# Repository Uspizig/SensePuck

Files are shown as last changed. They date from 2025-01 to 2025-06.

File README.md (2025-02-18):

# SensePuck: The Addon Board for the Seeed Round Display

<p align="center"> 
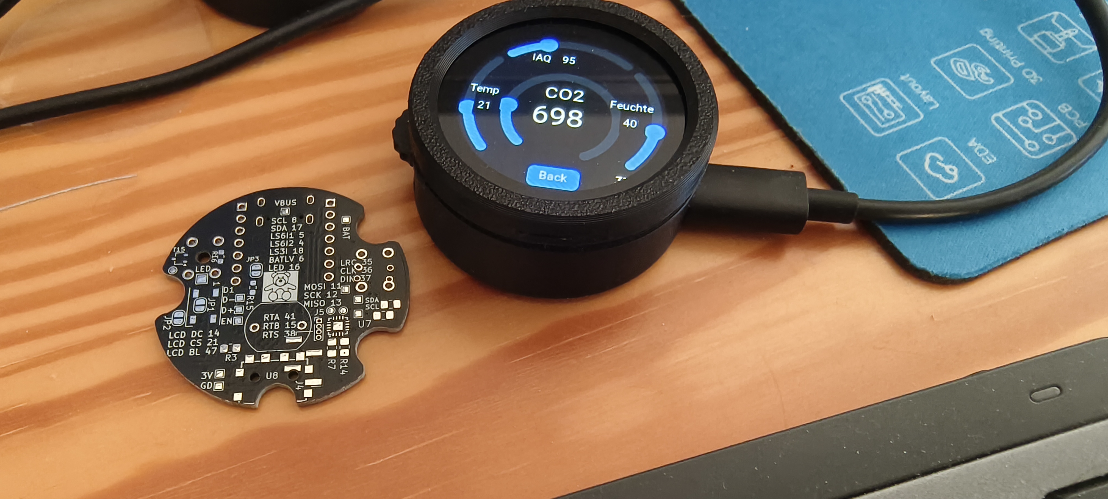
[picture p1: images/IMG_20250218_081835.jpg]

</p>

<p align="center"> 
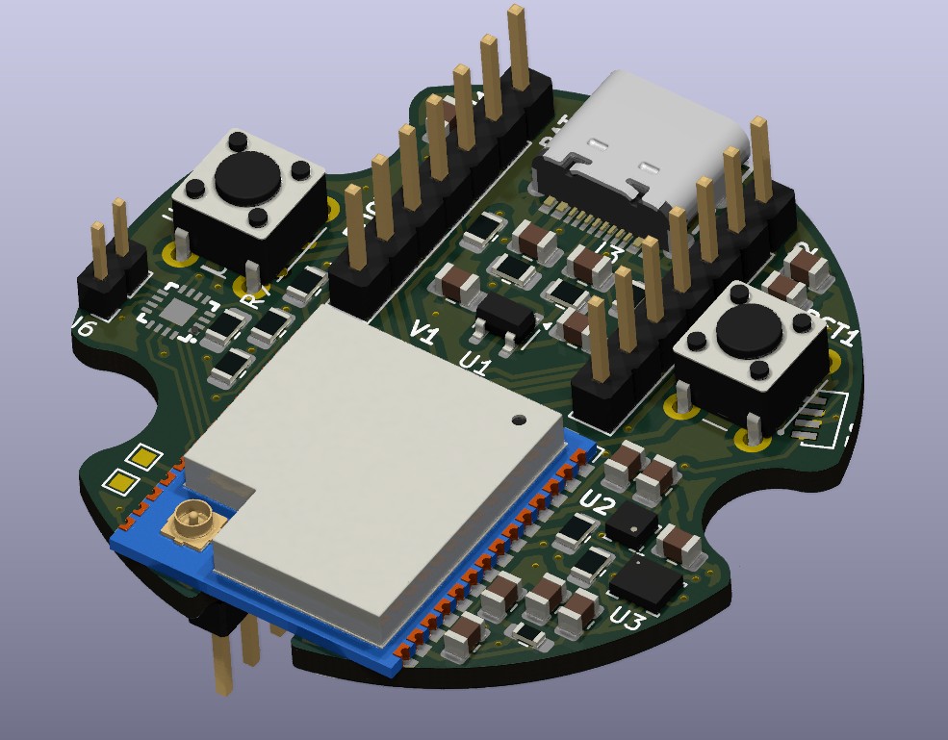
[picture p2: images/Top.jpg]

</p>

 <p align="center"> 
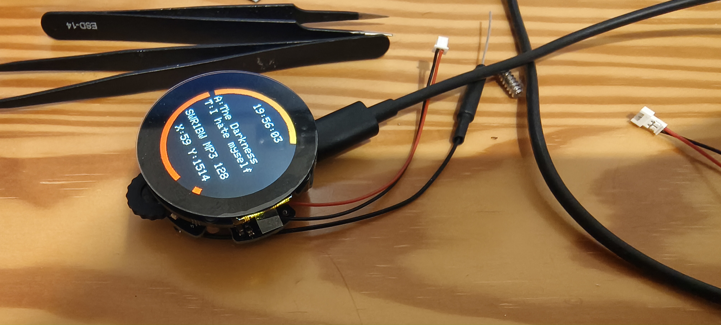
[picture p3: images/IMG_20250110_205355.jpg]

</p>

## Features:

1. **AudioAmplifier MAX98357**: Listen to your favourite Tunes with an Audio Amplifier

2. **I2C Connector for Sensor**: Connect your favourite I2C Sensor board with the embedded 2.54mm connector

3. **Wireless Control**: Untehther your development process with the wireless capabilities. With WiFi and BLE, this tool allows remote control and data logging. Users can adjust settings and monitor data from a distance, offering a more flexible development experience.

4. **LIS3M Magentometer**: Check your Heading

5. **LSM6 Gyro+ACC**: Check Movements, Steps Pedometer

5. **Open Source & Programmable**: As an open-source device, the Device offers unmatched versatility. It is fully programmable, allowing you to tailor its functionality to your specific applications. This customization extends to software and hardware, opening up endless possibilities for creative and efficient project development.

6. **Compact Design**: Designed for convenience, the LoRaCam Board compact and sleek form factor allows for seamless integration into existing setups. Its compatibility with USB PD power sources and inline integration capability minimizes the need for additional equipment or extensive redesign, making it a versatile and user-friendly addition to any development environment.

7. **Display+Touchscreeen**: Monitor live the current status on the Seeed Display

8. **RTC**: RealTimeClock from the Seeed Display
<p align="center"> 
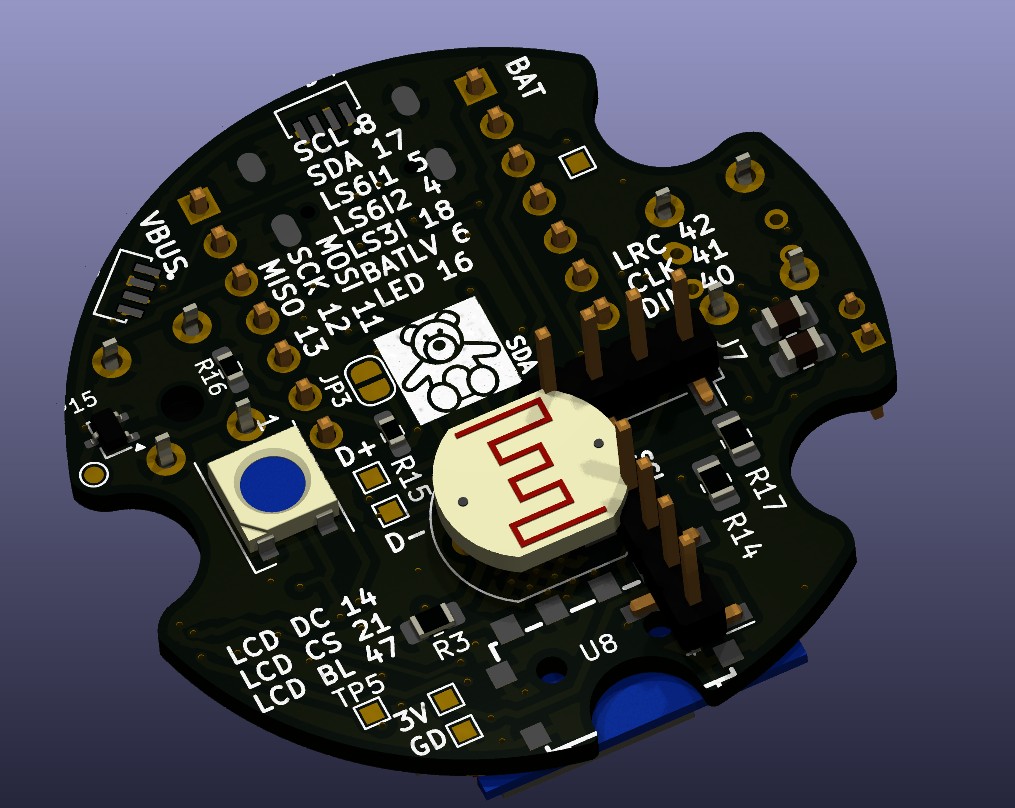
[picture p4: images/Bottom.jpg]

</p>

9. **RGB LED**: Status LED

10. **Battery Charger** Use the Battery Charger on the Seeed Display

11. **Rotary Encoder** Perfect for switching the Radio Station

12.  BME680: Measure Temperature, Humidity, Air Pressure, TVOC, eCO² (might update to BME688 or BME690 soon)
    
## Specifications

<p align="center"> 
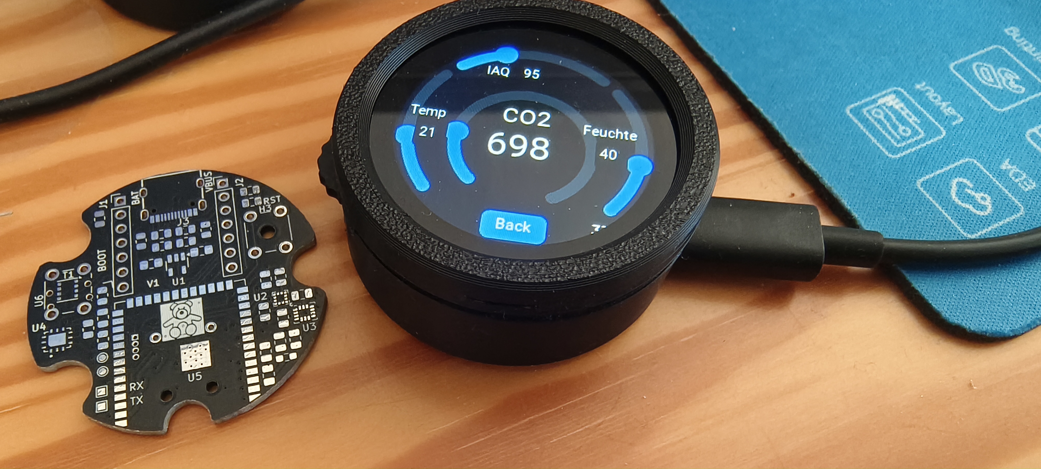
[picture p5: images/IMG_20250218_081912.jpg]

</p>

<p align="center"> 
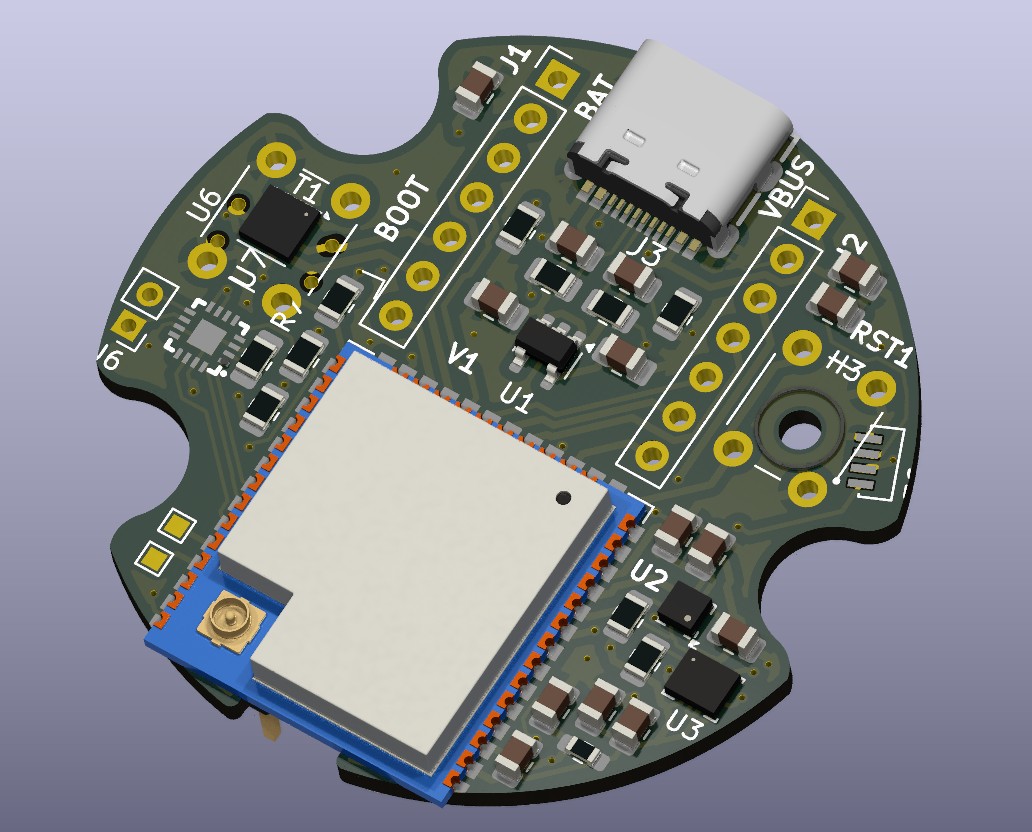
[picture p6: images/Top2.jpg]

</p>

<p align="center"> 
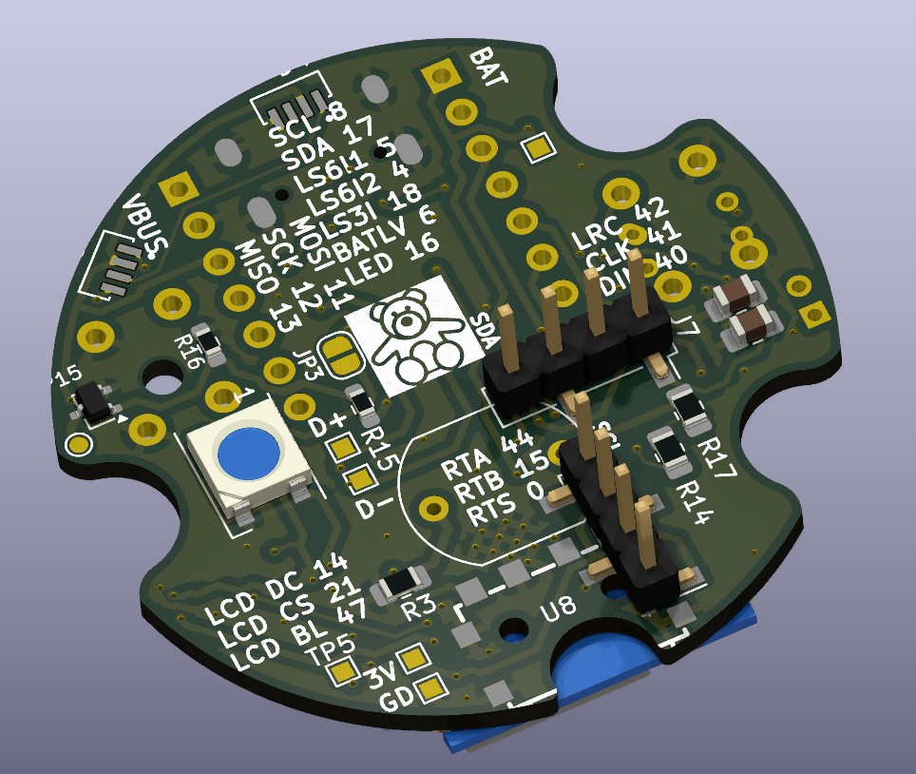
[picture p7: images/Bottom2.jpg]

</p>

<p align="center"> 
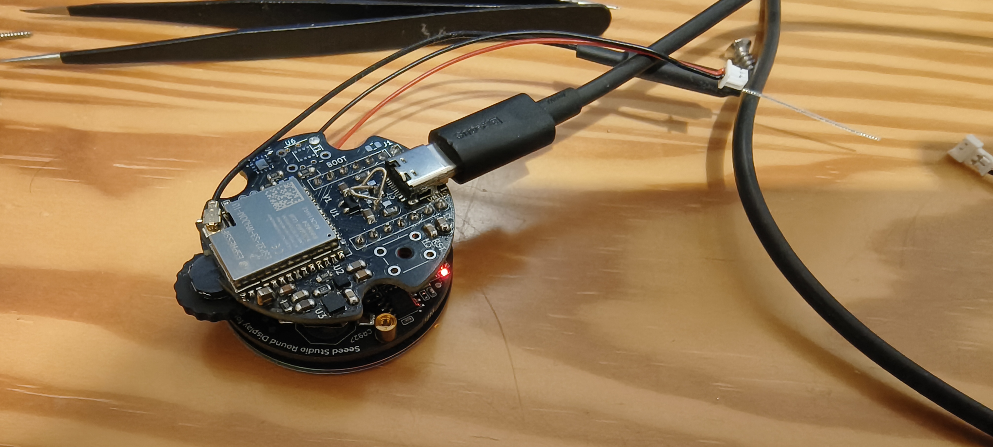
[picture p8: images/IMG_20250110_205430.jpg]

</p>

Needed Libaries:

https://github.com/schreibfaul1/ESP32-audioI2S
https://github.com/pololu/lis3mdl-arduino
https://github.com/pololu/lsm6-arduino
https://github.com/Seeed-Projects/SeeedStudio_TFT_eSPI
https://github.com/Seeed-Projects/SeeedStudio_lvgl
https://github.com/Seeed-Studio/Seeed_Arduino_RoundDisplay

### Key Features:

### Future Developments:

AI Detection of objects and determine if the device shall sent the data via LoRa 

## Testing for Performance

At the heart of SensePuck's design is a commitment to reliability and performance. To ensure that SensePuck stands up to real-world demands, we subjected it to testing under use conditions.

## License

MIT License

Copyright (c) 2025 blue2monster

Permission is hereby granted, free of charge, to any person obtaining a copy
of this software and associated documentation files (the "Software"), to deal
in the Software without restriction, including without limitation the rights
to use, copy, modify, merge, publish, distribute, sublicense, and/or sell
copies of the Software, and to permit persons to whom the Software is
furnished to do so, subject to the following conditions:

The above copyright notice and this permission notice shall be included in all
copies or substantial portions of the Software.

THE SOFTWARE IS PROVIDED "AS IS", WITHOUT WARRANTY OF ANY KIND, EXPRESS OR
IMPLIED, INCLUDING BUT NOT LIMITED TO THE WARRANTIES OF MERCHANTABILITY,
FITNESS FOR A PARTICULAR PURPOSE AND NONINFRINGEMENT. IN NO EVENT SHALL THE
AUTHORS OR COPYRIGHT HOLDERS BE LIABLE FOR ANY CLAIM, DAMAGES OR OTHER
LIABILITY, WHETHER IN AN ACTION OF CONTRACT, TORT OR OTHERWISE, ARISING FROM,
OUT OF OR IN CONNECTION WITH THE SOFTWARE OR THE USE OR OTHER DEALINGS IN THE
SOFTWARE.

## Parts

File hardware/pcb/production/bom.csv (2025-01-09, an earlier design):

Designator | Footprint | Quantity | Value | LCSC Part #
C1, C11, C12, C13, C14, C15, C16, C19, C6, C8, C9 | 0805 | 11 | 100nF
C10, C2, C3, C7 | 0805 | 4 | 1uF
C4, C5 | 0805 | 2 | DNP
D1 | LED_WS2812B_PLCC4_5.0x5.0mm_P3.2mm | 1 | WS2812B
J1 | PinHeader_1x07_P2.54mm_Vertical | 1 | DISP LEFT
J2 | PinHeader_1x07_P2.54mm_Vertical | 1 | DISP RIGHT
J3 | USB-C_SMD-TYPE-C-31-M-12 | 1 | TYPE-C-31-M-12
J4 | PinHeader_1x04_P2.54mm_Vertical_SMD_Pin1Left | 1 | Conn_01x04_Pin
J5 | PinHeader_1x04_P1.00mm_Vertical | 1 | Conn_01x04_Pin
JP3 | SolderJumper-2_P1.3mm_Open_RoundedPad1.0x1.5mm | 1 | Jumper_2_Small_Open
LED | TestPoint_Pad_1.5x1.5mm | 1 | LED
Q1 | SOT-323_SC-70 | 1 | SI1308EDL
R1, R15, R16 | 0603 | 3 | 10k
R10, R11, R12, R13, R4 | 0805 | 5 | 10k
R14 | 0805 | 1 | 300k
R2 | R_LDR_10x8.5mm_P7.6mm_Vertical | 1 | LDR03
R3 | 0805 | 1 | N.C.
R5, R6 | 0805 | 2 | 5k1
R7 | 0805 | 1 | 100K
R8, R9 | 0805 | 2 | 22R
RST | SW_PUSH_6mm | 1 | RST
RX | TestPoint_Pad_1.0x1.0mm | 1 | RXD
SW1 | SW_PUSH_6mm | 1 | BOOT
T1 | MLX90640 | 1 | MLX90640
T15, TP11, TP12, TP13, TP14 | TestPoint_Pad_D1.0mm | 5 | TestPoint
TP1 | TestPoint_Pad_1.0x1.0mm | 1 | D-
TP10 | TestPoint_Pad_1.0x1.0mm | 1 | BATT
TP2 | TestPoint_Pad_1.0x1.0mm | 1 | D+
TP3 | TestPoint_Pad_1.0x1.0mm | 1 | 3V3
TP4 | TestPoint_Pad_1.0x1.0mm | 1 | GND
TP5 | TestPoint_Pad_1.0x1.0mm | 1 | EN
TP6 | TestPoint_Pad_1.0x1.0mm | 1 | IO0
TP7 | TestPoint_Pad_1.0x1.0mm | 1 | SCL
TP8 | TestPoint_Pad_1.0x1.0mm | 1 | SDA
TP9 | TestPoint_Pad_1.0x1.0mm | 1 | VBUS
TX | TestPoint_Pad_1.0x1.0mm | 1 | TXD
U1 | SOT-23-5 | 1 | RT9013
U2 | LGA-12_2x2mm_P0.5mm | 1 | LIS3MDL
U3 | LGA-14_3x2.5mm_P0.5mm_LayoutBorder3x4y | 1 | LSM6DSOWTR
U4 | XDCR_STC31-C-R3 | 1 | STC31-C-R3
U5 | ESP32-S3-WROOM-1 | 1 | ESP32-S3-WROOM-1-Espressif
U6 | Bosch_LGA-8_3x3mm_P0.8mm_ClockwisePinNumbering | 1 | BME680
U7 | TQFN-16_L3.0-W3.0-P0.50-BL-EP1.5 | 1 | ~
U8 | SW-SMD_SIQ-02FVS3_1 | 1 | ~

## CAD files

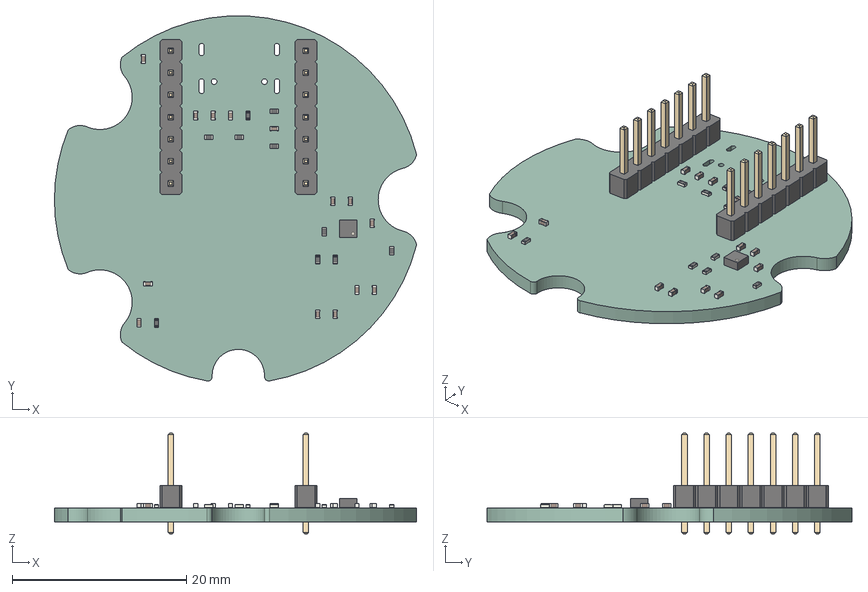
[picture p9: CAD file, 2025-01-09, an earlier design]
hardware/pcb/sensor_puck.step
41.6 x 41.9 x 11.5 mm
PinHeader_1x07_P254mm_Vertical x 2
C_0402_1005Metric x 14
R_0402_1005Metric x 10
LGA_12_2x2mm_P05mm
sensor_puck_PCB

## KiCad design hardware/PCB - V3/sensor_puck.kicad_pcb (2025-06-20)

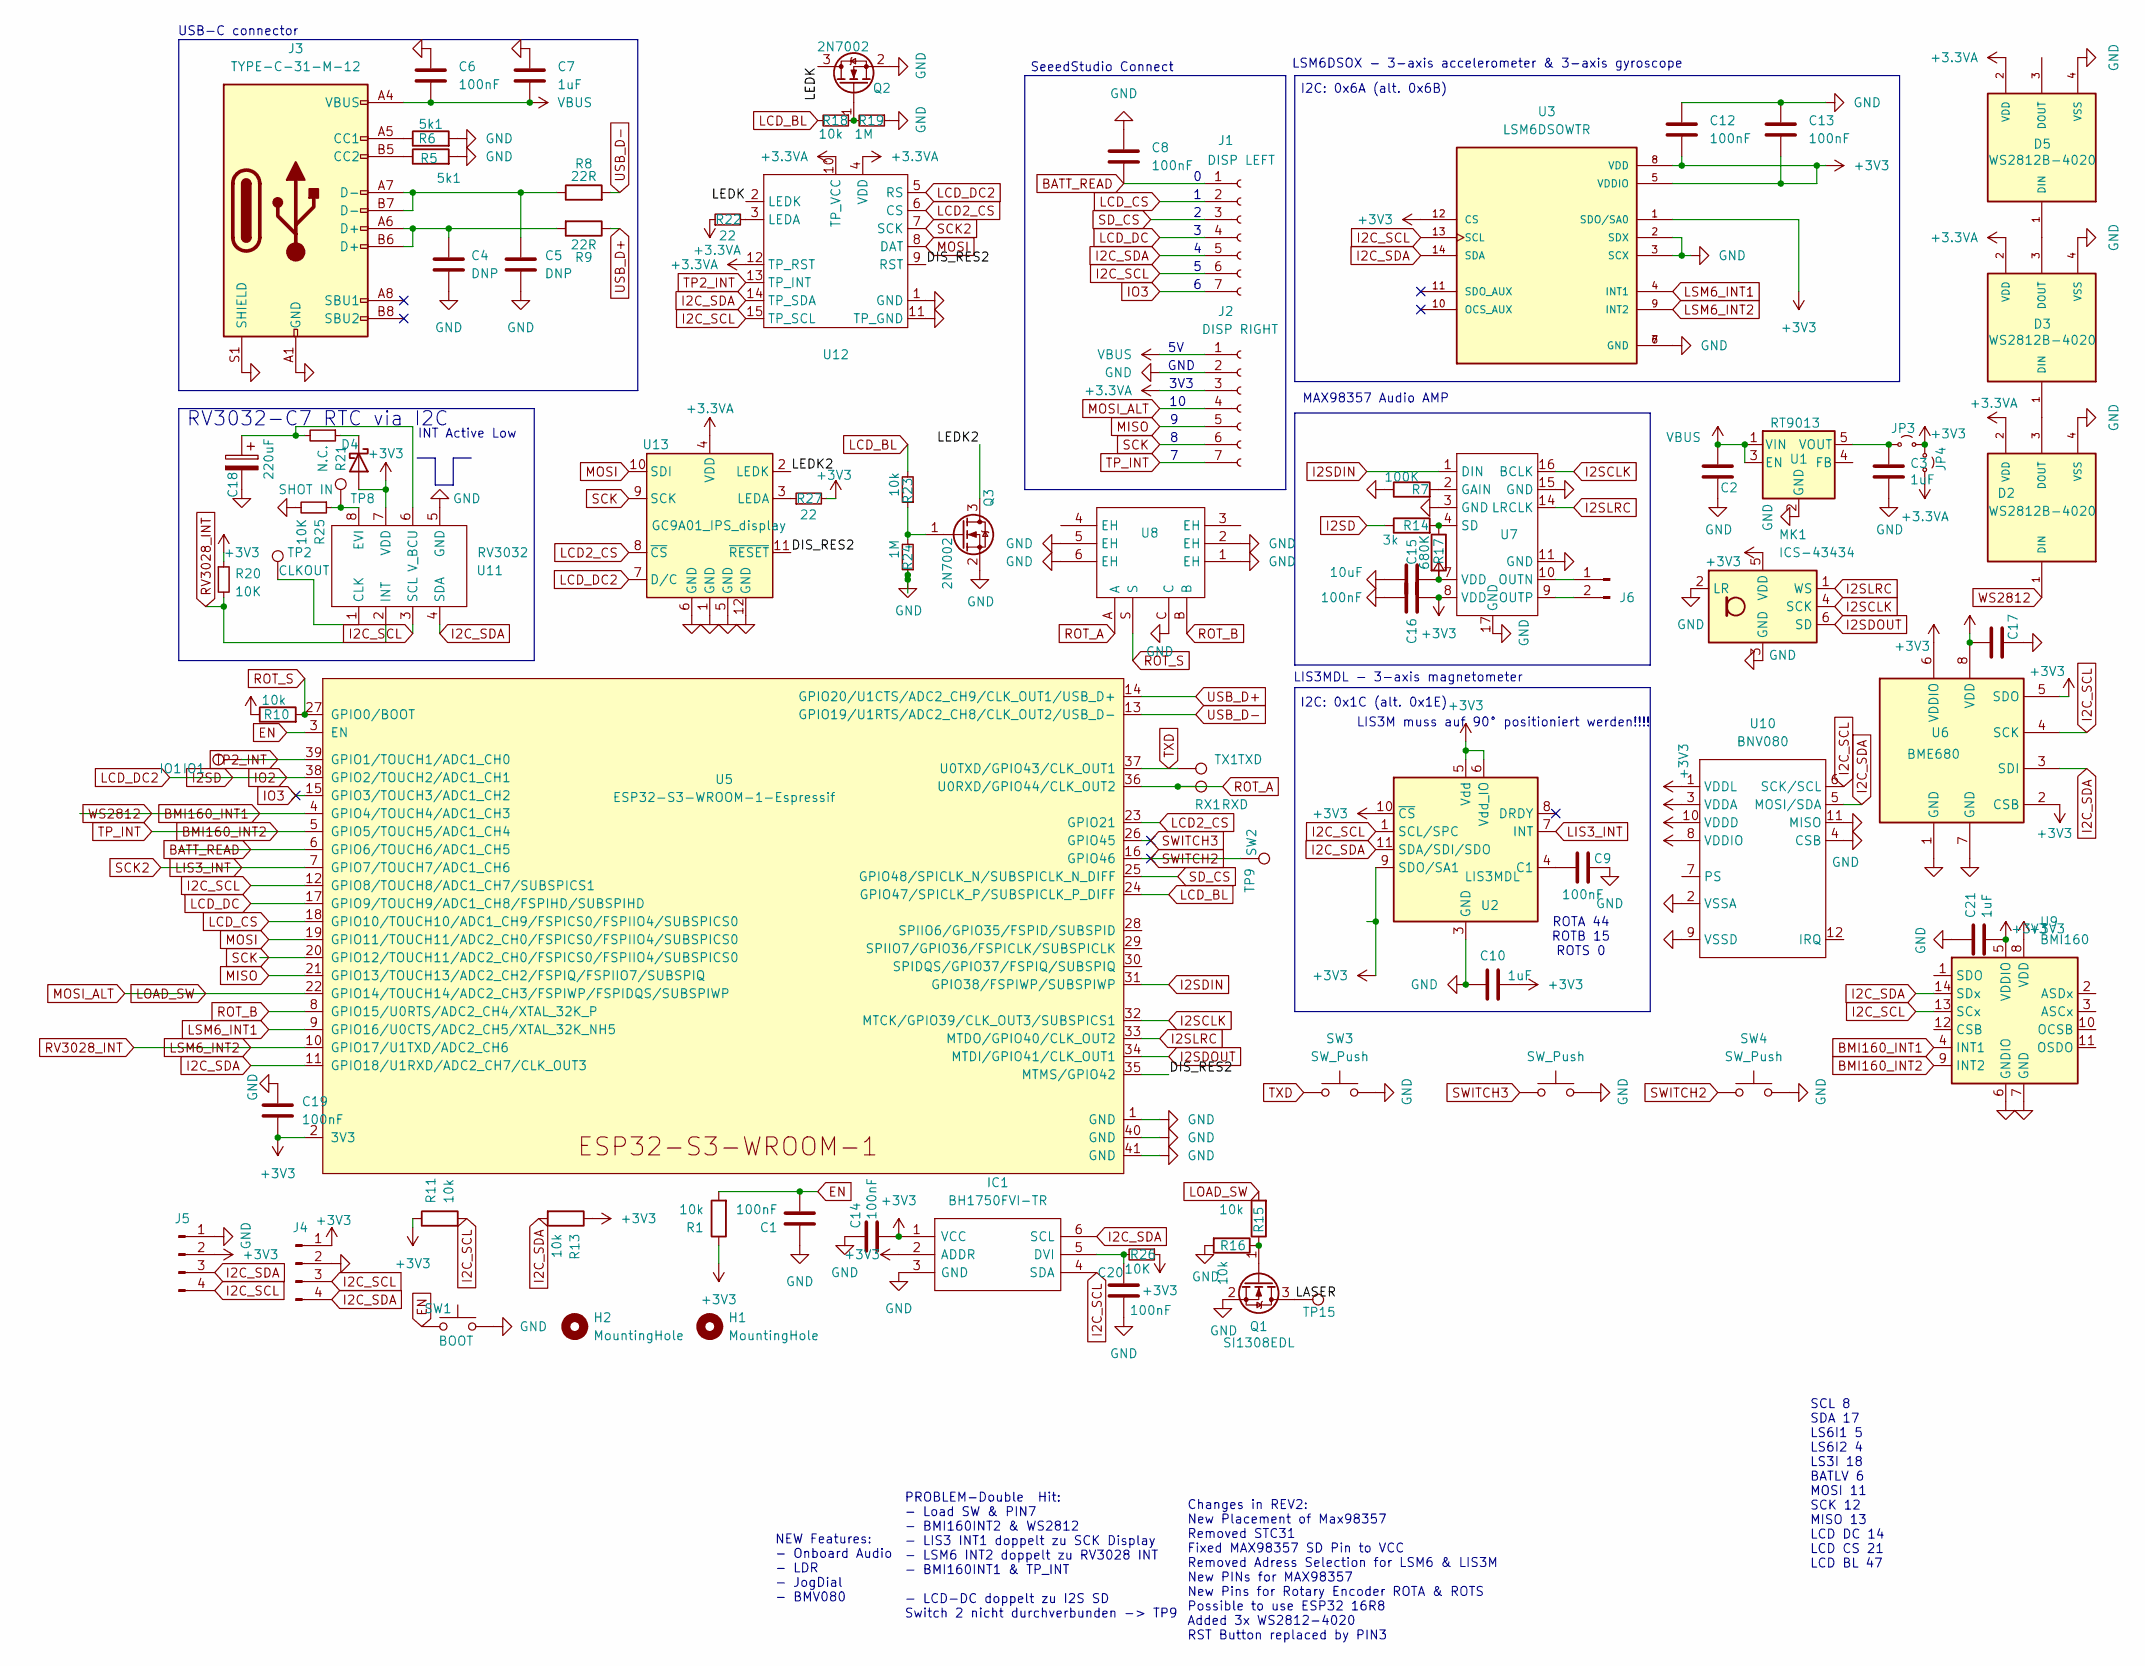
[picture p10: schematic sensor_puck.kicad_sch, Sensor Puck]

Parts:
C1: 100nF; C_1206_3216Metric_Pad1.33x1.80mm_HandSolder
C2, C3, C17, C21: 1uF; C_0805_2012Metric_Pad1.18x1.45mm_HandSolder
C4, C5: DNP; C_0805_2012Metric
C6, C8, C9, C12, C13, C14, C19: 100nF; C_0805_2012Metric
C7, C10: 1uF; C_0805_2012Metric
C15: 10uF; C_0805_2012Metric_Pad1.18x1.45mm_HandSolder
C16: 100nF; C_0805_2012Metric_Pad1.18x1.45mm_HandSolder
C18: 220uF; CP_EIA-3528-21_Kemet-B
C20: 100nF; C_0603_1608Metric
D2, D3, D5: WS2812B-4020; LED_WS2812B-4020; PARTREV V1.2
D4: MBR0530; D_SOD-323F
H1, H2: MountingHole; baerklein
IC1: BH1750FVI-TR; WSOF6; Mouser Part Number 755-BH1750FVI-TR
IO1: IO1; TestPoint_Pad_1.0x1.0mm
J1: DISP LEFT; PinHeader_1x07_P2.54mm_Vertical
J2: DISP RIGHT; PinHeader_1x07_P2.54mm_Vertical
J3: TYPE-C-31-M-12; USB-C_SMD-TYPE-C-31-M-12
J4: Conn_01x04_Pin; PinHeader_1x04_P2.54mm_Vertical_SMD_Pin1Left
J5: Conn_01x04_Pin; JST_SH_SM04B-SRSS-TB_1x04-1MP_P1.00mm_Horizontal
J6: Conn_01x02_Pin; PinHeader_1x02_P2.00mm_Vertical
JP3, JP4: Jumper_2_Small_Open; SolderJumper-2_P1.3mm_Open_RoundedPad1.0x1.5mm
MK1: ICS-43434; InvenSense_ICS-43434-6_3.5x2.65mm
Q1: SI1308EDL; SOT-323_SC-70
Q2, Q3: 2N7002; SOT-23
R1: 10k; R_0805_2012Metric_Pad1.20x1.40mm_HandSolder
R5, R6: 5k1; R_0805_2012Metric
R7: 100K; R_0805_2012Metric_Pad1.20x1.40mm_HandSolder
R8, R9: 22R; R_0805_2012Metric
R10, R11, R13: 10k; R_0805_2012Metric
R14: 3k; R_0805_2012Metric_Pad1.20x1.40mm_HandSolder
R15, R16: 10k; R_0603_1608Metric_Pad0.98x0.95mm_HandSolder
R17: 680K; R_0805_2012Metric_Pad1.20x1.40mm_HandSolder
R18, R23: 10k; R_0603_1608Metric
R19, R24: 1M; R_0603_1608Metric
R20, R25, R26: 10K; R_0603_1608Metric_Pad0.98x0.95mm_HandSolder; LCSC C17414
R21: N.C.; C_0603_1608Metric
R22, R27: 22; R_0603_1608Metric
RX1: RXD; TestPoint_Pad_1.0x1.0mm
SW1: BOOT; SW_PUSH_6mm
SW3, SW4, SW6: SW_Push; SW_SPST_CK_KMS2xxGP
TP2: CLKOUT; TestPoint_Pad_D1.0mm
TP8: SHOT IN; TestPoint_Pad_D1.0mm
TP9: SW2; TestPoint_Pad_D1.0mm
TP15: TestPoint; TestPoint_Pad_D1.0mm
TX1: TXD; TestPoint_Pad_1.0x1.0mm
U1: RT9013; SOT-23-5
U2: LIS3MDL; LGA-12_2x2mm_P0.5mm
U3: LSM6DSOWTR; LGA-14_3x2.5mm_P0.5mm_LayoutBorder3x4y; PARTREV 3.0
U5: ESP32-S3-WROOM-1-Espressif; ESP32-S3-WROOM-1
U6: BME680; Bosch_LGA-8_3x3mm_P0.8mm_ClockwisePinNumbering
U7: TQFN-16_L3.0-W3.0-P0.50-BL-EP1.5
U8: SW-SMD_SIQ-02FVS3_1; Manufacturer Part SIQ-02FVS3; LCSC Part Name 拨轮滚轮旋转编码器开关
U9: BMI160; Bosch_LGA-14_3x2.5mm_P0.5mm
U10: BNV080; 046844713002846
U11: RV3032; MicroCrystal_C7_SON-8_1.5x3.2mm_P0.9mm
U12: GC9A01_Touch_IPS_display_reversed_16pin
U13: GC9A01_IPS_display; GC9A01_IPS_display_reversed

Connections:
+3.3VA: D2.2 (VDD), D3.2 (VDD), D5.2 (VDD), J2.3, JP4.2 (B), R22.1, U12.4 (VDD), U12.10 (TP_VCC), U12.12 (TP_RST), U13.4 (VDD)
+3V3: C10.2, C12.2, C13.2, C14.2, C15.1, C16.1, C17.2, C19.2, C21.1, D4.2 (A), IC1.1 (VCC), IC1.2 (ADDR), J4.1, J5.2, JP3.2 (B), JP4.1 (A), MK1.5 (VDD), R1.1, R10.1, R11.1, R13.1, R17.2, R20.1, R26.1, R27.2, U2.5 (Vdd), U2.6 (Vdd_IO), U2.9 (SDO/SA1), U2.10 (~CS), U3.1 (SDO/SA0), U3.5 (VDDIO), U3.8 (VDD), U3.12 (CS), U5.2 (3V3), U6.2 (CSB), U6.5 (SDO), U6.6 (VDDIO), U6.8 (VDD), U7.7 (VDD), U7.8 (VDD), U9.5 (VDDIO), U9.8 (VDD), U10.1 (VDDL), U10.3 (VDDA), U10.8 (VDDIO), U10.10 (VDDD), U11.7 (VDD)
/DIS_RES2: U5.35 (MTMS/GPIO42), U12.9 (RST), U13.11 (~RESET)
/LASER: Q1.3 (D), TP15.1
/LEDK: Q2.3 (D), U12.2 (LEDK)
/LEDK2: Q3.3 (D), U13.2 (LEDK)
BATT_READ: C8.1, J1.1, U5.6 (GPIO6/TOUCH6/ADC1_CH5)
BMI160_INT1: D2.1 (DIN), U5.4 (GPIO4/TOUCH4/ADC1_CH3), U9.4 (INT1)
BMI160_INT2: J2.7, U5.5 (GPIO5/TOUCH5/ADC1_CH4), U9.9 (INT2)
EN: C1.2, R1.2, SW1.1, U5.3 (EN)
GND: C1.1, C2.1, C3.1, C4.2, C5.2, C6.1, C7.1, C8.2, C9.2, C10.1, C12.1, C13.1, C14.1, C15.2, C16.2, C17.1, C18.2, C19.1, C20.2, C21.2, D2.4 (VSS), D3.4 (VSS), D5.4 (VSS), IC1.3 (GND), J2.2, J3.A1 (GND), J3.A12 (GND), J3.B1 (GND), J3.B12 (GND), J3.S1 (SHIELD), J4.2, J5.1, MK1.2 (LR), MK1.3 (GND), Q1.2 (S), Q2.2 (S), Q3.2 (S), R5.2, R6.2, R7.1, R16.2, R19.1, R24.1, R25.2, SW1.2, SW3.2, SW4.2, SW6.2, U1.2 (GND), U2.2 (GND), U2.3 (GND), U2.12 (GND), U3.2 (SDX), U3.3 (SCX), U3.6 (GND), U3.7 (GND), U5.1 (GND), U5.40 (GND), U5.41 (GND), U6.1 (GND), U6.7 (GND), U7.3 (GND), U7.11 (GND), U7.15 (GND), U7.17 (GND), U8.1 (EH), U8.2 (EH), U8.5 (EH), U8.6 (EH), U8.C, U9.6 (GNDIO), U9.7 (GND), U10.2 (VSSA), U10.4 (CSB), U10.9 (VSSD), U10.11 (MISO), U11.5 (GND), U12.1 (GND), U12.11 (TP_GND), U13.1 (GND), U13.5 (GND), U13.6 (GND), U13.12 (GND)
I2C_SCL: IC1.4 (SDA), J1.6, J4.3, J5.4, R11.2, U2.1 (SCL/SPC), U3.13 (SCL), U5.12 (GPIO8/TOUCH8/ADC1_CH7/SUBSPICS1), U6.4 (SCK), U9.13 (SCx), U10.6 (SCK/SCL), U11.3 (SCL), U12.15 (TP_SCL)
I2C_SDA: IC1.6 (SCL), J1.5, J4.4, J5.3, R13.2, U2.11 (SDA/SDI/SDO), U3.14 (SDA), U5.11 (GPIO18/U1RXD/ADC2_CH7/CLK_OUT3), U6.3 (SDI), U9.14 (SDx), U10.5 (MOSI/SDA), U11.4 (SDA), U12.14 (TP_SDA)
I2SCLK: MK1.4 (SCK), U5.32 (MTCK/GPIO39/CLK_OUT3/SUBSPICS1), U7.16 (BCLK)
I2SD: R14.1, U5.38 (GPIO2/TOUCH2/ADC1_CH1), U12.5 (RS), U13.7 (D/C)
I2SDIN: U5.31 (GPIO38/FSPIWP/SUBSPIWP), U7.1 (DIN)
I2SDOUT: MK1.6 (SD), U5.34 (MTDI/GPIO41/CLK_OUT1)
I2SLRC: MK1.1 (WS), U5.33 (MTDO/GPIO40/CLK_OUT2), U7.14 (LRCLK)
IO3: J1.7, U5.15 (GPIO3/TOUCH3/ADC1_CH2)
LCD2_CS: U5.23 (GPIO21), U12.6 (CS), U13.8 (~CS)
LCD_BL: R18.2, R23.2, U5.24 (GPIO47/SPICLK_P/SUBSPICLK_P_DIFF)
LCD_CS: J1.2, U5.18 (GPIO10/TOUCH10/ADC1_CH9/FSPICS0/FSPIIO4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)
LCD_DC: J1.4, U5.17 (GPIO9/TOUCH9/ADC1_CH8/FSPIHD/SUBSPIHD)
LIS3_INT: U2.7 (INT), U5.7 (GPIO7/TOUCH7/ADC1_CH6), U12.7 (SCK)
LOAD_SW: J2.4, R15.2, U5.22 (GPIO14/TOUCH14/ADC2_CH3/FSPIWP/FSPIDQS/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)
LSM6_INT1: U3.4 (INT1), U5.9 (GPIO16/U0CTS/ADC2_CH5/XTAL_32K_NH5)
LSM6_INT2: R20.2, U3.9 (INT2), U5.10 (GPIO17/U1TXD/ADC2_CH6), U11.2 (INT)
MISO: J2.5, U5.21 (GPIO13/TOUCH13/ADC2_CH2/FSPIQ/FSPIIO7/S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)
MOSI: U5.19 (GPIO11/TOUCH11/ADC2_CH0/FSPICS0/FSPIIO4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), U12.8 (DAT), U13.10 (SDI)
unnamed: C4.1, J3.A6 (D+), J3.B6 (D+), R9.2
unnamed: C5.1, J3.A7 (D-), J3.B7 (D-), R8.1
unnamed: D2.3 (DOUT), D3.1 (DIN)
unnamed: D3.3 (DOUT), D5.1 (DIN)
unnamed: D4.1 (K), R21.1
unnamed: C20.1, IC1.5 (DVI), R26.2
unnamed: J3.A5 (CC1), R6.1
unnamed: J3.B5 (CC2), R5.1
unnamed: J6.1, U7.10 (OUTN)
unnamed: J6.2, U7.9 (OUTP)
unnamed: C3.2, JP3.1 (A), U1.5 (VOUT)
unnamed: Q1.1 (G), R15.1, R16.1
unnamed: Q2.1 (G), R18.1, R19.2
unnamed: Q3.1 (G), R23.1, R24.2
unnamed: C9.1, U2.4 (C1)
unnamed: R7.2, U7.2 (GAIN)
unnamed: R14.2, R17.1, U7.4 (SD)
unnamed: TP2.1, U11.1 (CLK)
unnamed: R25.1, TP8.1, U11.8 (EVI)
unnamed: C18.1, R21.2, U11.6 (V_BCU)
unnamed: R22.2, U12.3 (LEDA)
unnamed: R27.1, U13.3 (LEDA)
ROT_A: RX1.1, U5.36 (U0RXD/GPIO44/CLK_OUT2), U8.A
ROT_B: U5.8 (GPIO15/U0RTS/ADC2_CH4/XTAL_32K_P), U8.B
ROT_S: R10.2, U5.27 (GPIO0/BOOT), U8.S
SCK: J2.6, U5.20 (GPIO12/TOUCH11/ADC2_CH0/FSPICS0/FSPIIO4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), U13.9 (SCK)
SD_CS: J1.3, U5.25 (GPIO48/SPICLK_N/SUBSPICLK_N_DIFF)
SWITCH3: SW6.1, U5.26 (GPIO45)
TP2_INT: IO1.1, U5.39 (GPIO1/TOUCH1/ADC1_CH0), U12.13 (TP_INT)
TXD: SW3.1, TX1.1, U5.37 (U0TXD/GPIO43/CLK_OUT1)
USB_D+: R9.1, U5.14 (GPIO20/U1CTS/ADC2_CH9/CLK_OUT1/USB_D+)
USB_D-: R8.2, U5.13 (GPIO19/U1RTS/ADC2_CH8/CLK_OUT2/USB_D-)
VBUS: C2.2, C6.2, C7.2, J2.1, J3.A4 (VBUS), J3.A9 (VBUS), J3.B4 (VBUS), J3.B9 (VBUS), U1.1 (VIN), U1.3 (EN)

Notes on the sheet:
USB-C connector
PROBLEM-Double Hit: - Load SW & PIN7 - BMI160INT2 & WS2812 - LIS3 INT1 doppelt zu SCK Display - LSM6 INT2 doppelt zu RV3028 INT - BMI160INT1 & TP_INT - LCD-DC doppelt zu I2S SD Switch 2 nicht durchverbunden -> TP9
INT Active Low
LIS3M muss auf 90° positioniert werden!!!!
SeeedStudio Connect
SCL 8 SDA 17 LS6I1 5 LS6I2 4 LS3I 18 BATLV 6 MOSI 11 SCK 12 MISO 13 LCD DC 14 LCD CS 21 LCD BL 47
I2C: 0x1C (alt. 0x1E)
NEW Features: - Onboard Audio - LDR - JogDial - BMV080
Changes in REV2: New Placement of Max98357 Removed STC31 Fixed MAX98357 SD Pin to VCC Removed Adress Selection for LSM6 & LIS3M New PINs for MAX98357 New Pins for Rotary Encoder ROTA & ROTS Possible to use ESP32 16R8 Added 3x WS2812-4020 RST Button replaced by PIN3
I2C: 0x6A (alt. 0x6B)
LIS3MDL - 3-axis magnetometer
RV3032-C7 RTC via I2C
MAX98357 Audio AMP
GND
LSM6DSOX - 3-axis accelerometer & 3-axis gyroscope
ROTA 44 ROTB 15 ROTS 0
3V3

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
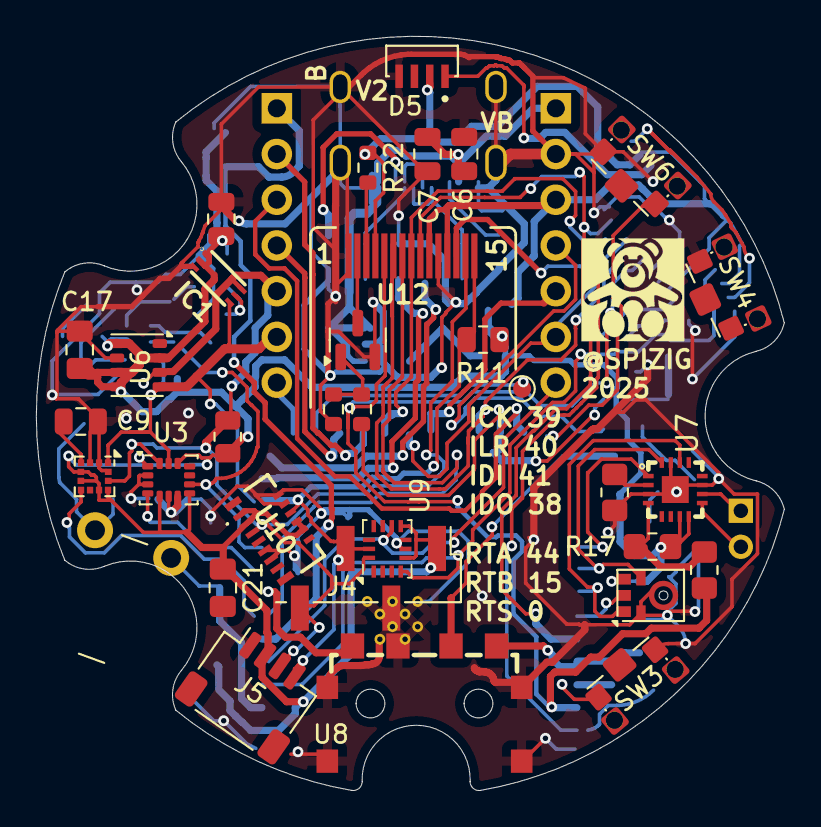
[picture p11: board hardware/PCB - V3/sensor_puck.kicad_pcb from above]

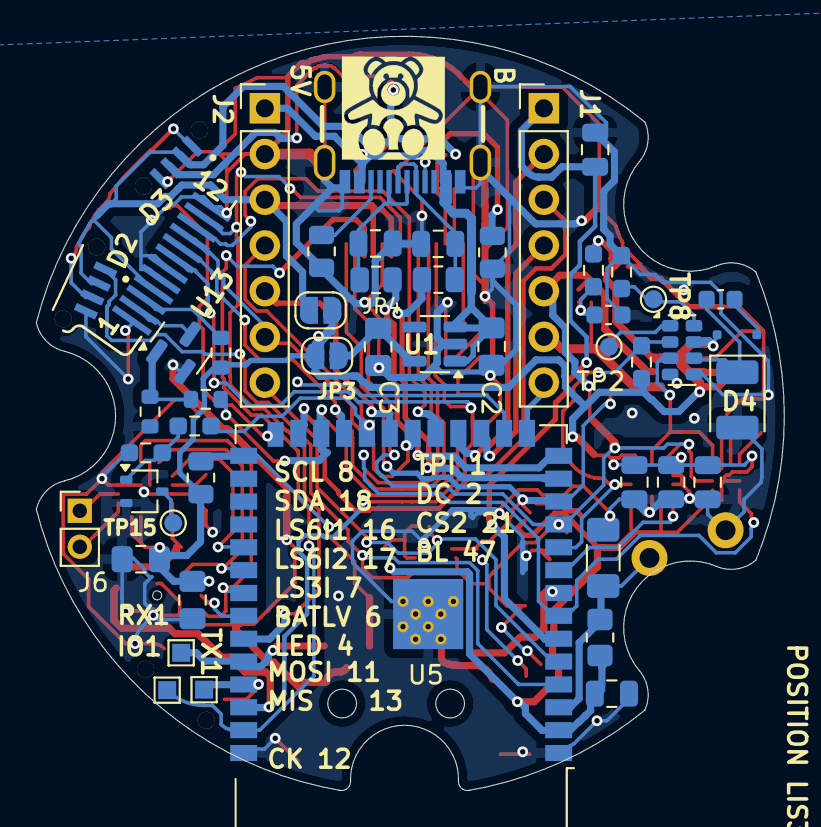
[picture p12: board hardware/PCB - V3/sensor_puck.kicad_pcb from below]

Board: 2 copper layers, 41.6 x 41.9 mm, 85 parts (51 on the bottom side), 63 nets.

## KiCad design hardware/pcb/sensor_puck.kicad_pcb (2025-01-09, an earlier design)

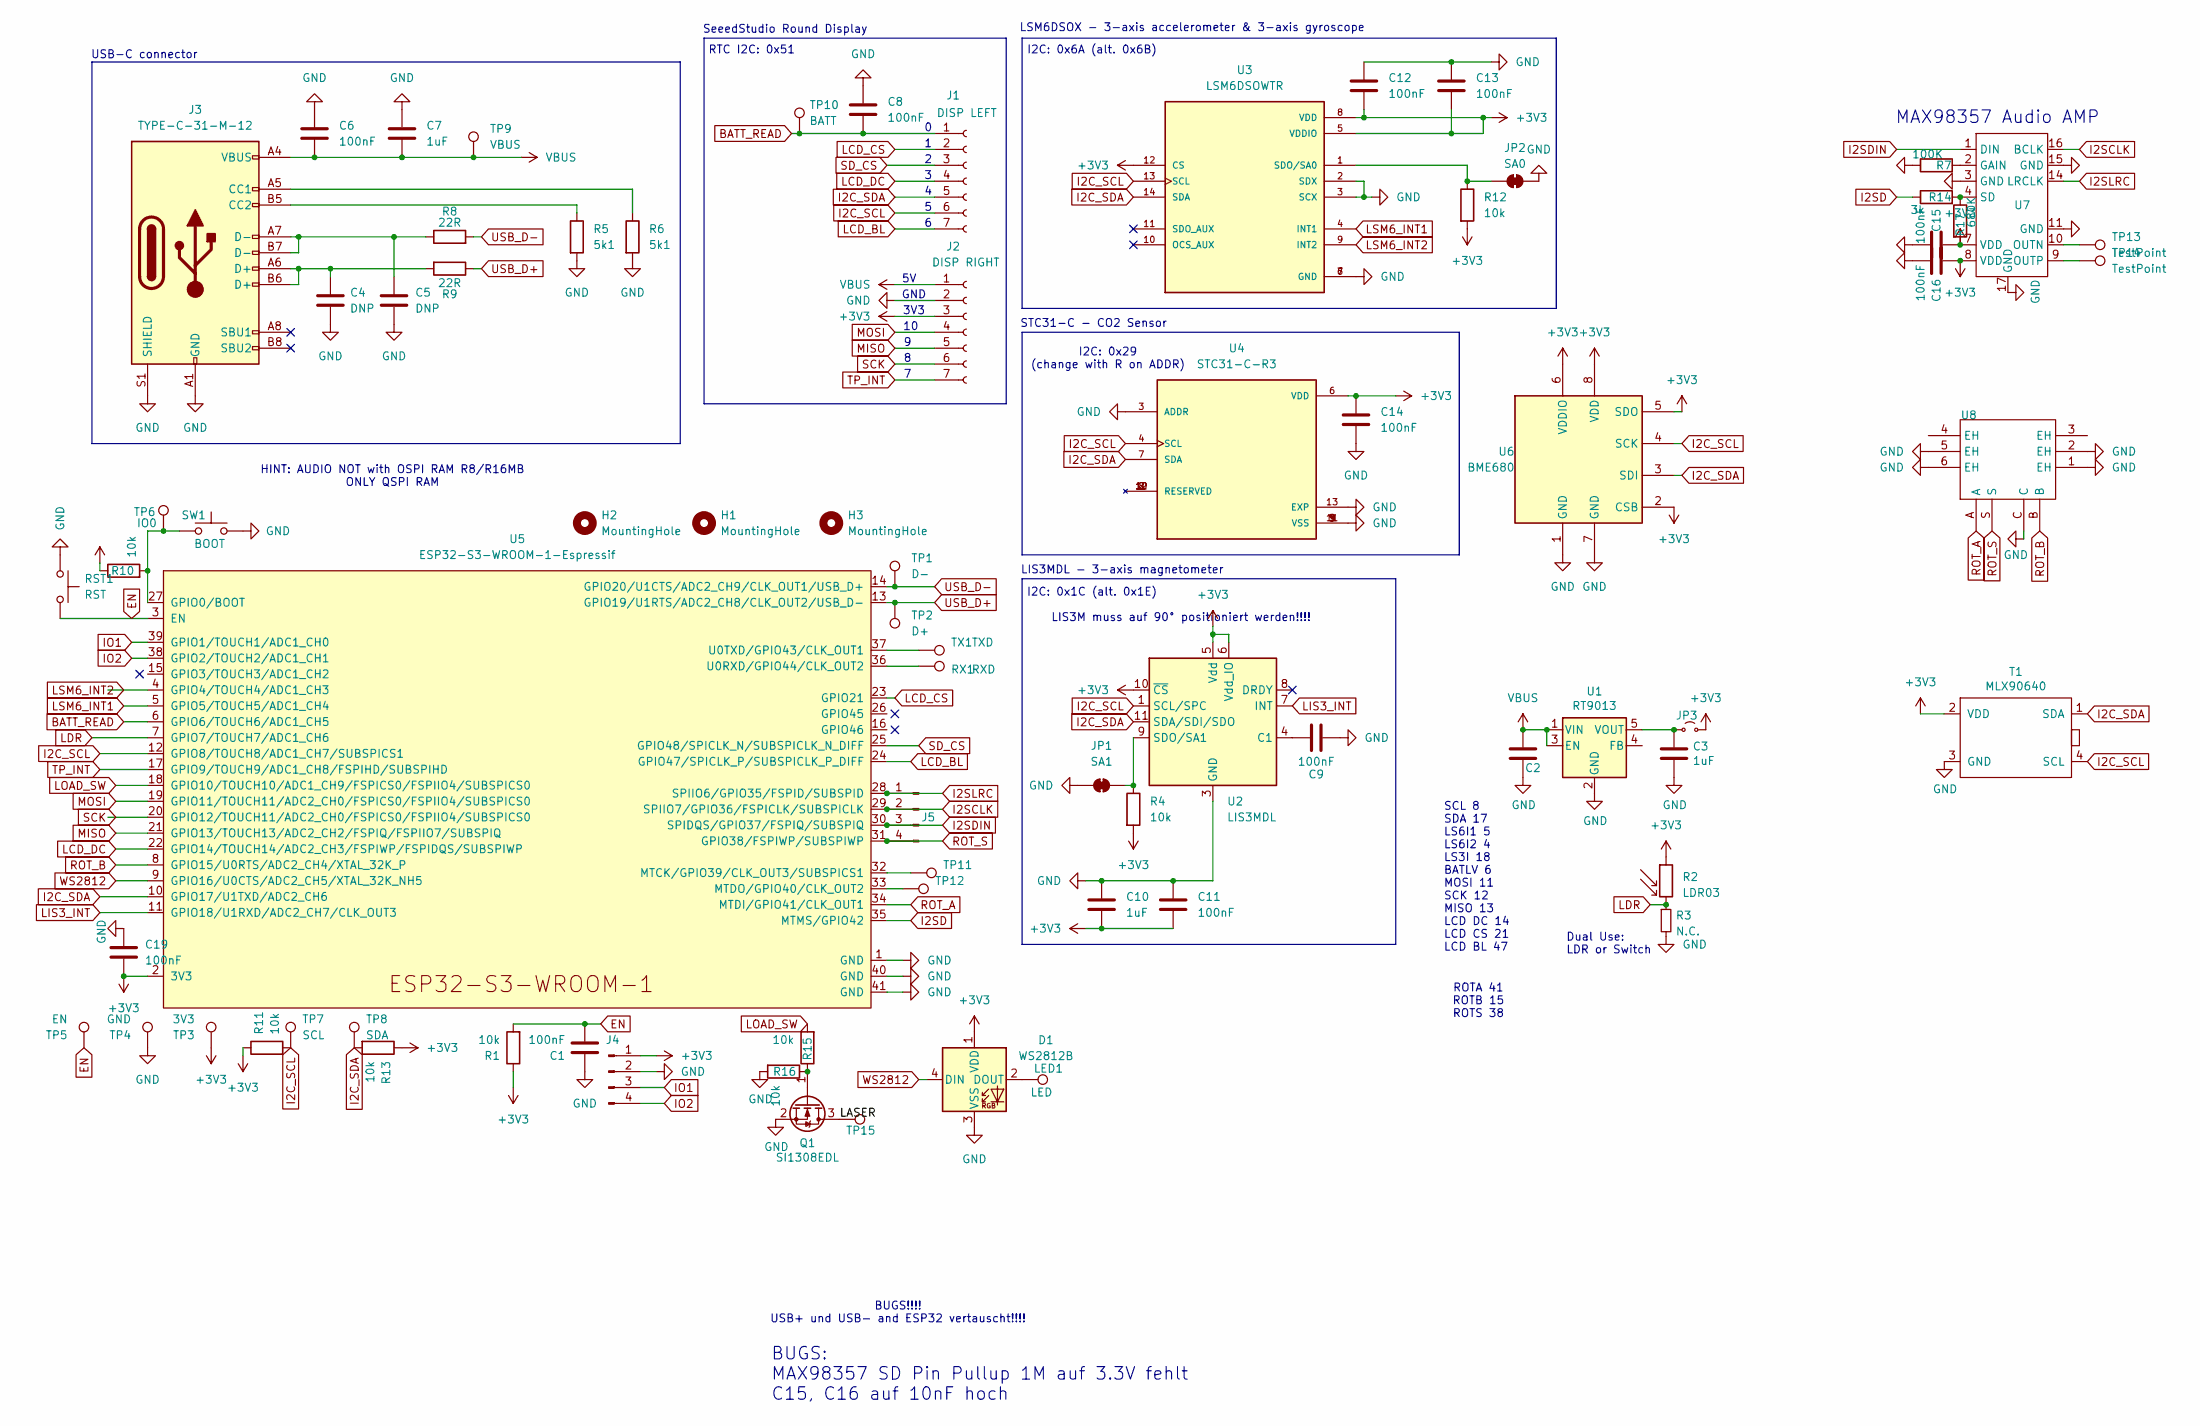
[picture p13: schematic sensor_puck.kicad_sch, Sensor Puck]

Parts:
C1, C6, C8, C9, C11, C12, C13, C14, C19: 100nF; C_0805_2012Metric
C2, C3: 1uF; C_0805_2012Metric_Pad1.18x1.45mm_HandSolder
C4, C5: DNP; C_0805_2012Metric
C7, C10: 1uF; C_0805_2012Metric
C15, C16: 100nF; C_0805_2012Metric_Pad1.18x1.45mm_HandSolder
D1: WS2812B; LED_WS2812B_PLCC4_5.0x5.0mm_P3.2mm
H1, H2: MountingHole; baerklein
H3: MountingHole; MountingHole_2.2mm_M2
J1: DISP LEFT; PinHeader_1x07_P2.54mm_Vertical
J2: DISP RIGHT; PinHeader_1x07_P2.54mm_Vertical
J3: TYPE-C-31-M-12; USB-C_SMD-TYPE-C-31-M-12
J4: Conn_01x04_Pin; PinHeader_1x04_P2.54mm_Vertical_SMD_Pin1Left
J5: Conn_01x04_Pin; PinHeader_1x04_P1.00mm_Vertical
JP1: SA1; SolderJumper-2_P1.3mm_Open_RoundedPad1.0x1.5mm
JP2: SA0; SolderJumper-2_P1.3mm_Open_RoundedPad1.0x1.5mm
JP3: Jumper_2_Small_Open; SolderJumper-2_P1.3mm_Open_RoundedPad1.0x1.5mm
LED1: LED; TestPoint_Pad_1.5x1.5mm
Q1: SI1308EDL; SOT-323_SC-70
R1, R15, R16: 10k; R_0603_1608Metric_Pad0.98x0.95mm_HandSolder
R2: LDR03; R_LDR_10x8.5mm_P7.6mm_Vertical
R3: N.C.; R_0805_2012Metric_Pad1.20x1.40mm_HandSolder
R4, R10, R11, R12, R13: 10k; R_0805_2012Metric
R5, R6: 5k1; R_0805_2012Metric
R7: 100K; R_0805_2012Metric_Pad1.20x1.40mm_HandSolder
R8, R9: 22R; R_0805_2012Metric
R14: 3k; R_0805_2012Metric_Pad1.20x1.40mm_HandSolder
R17: 680K; R_0805_2012Metric_Pad1.20x1.40mm_HandSolder
RST1: RST; SW_PUSH_6mm
RX1: RXD; TestPoint_Pad_1.0x1.0mm
SW1: BOOT; SW_PUSH_6mm
T1: MLX90640; Part Number 482-MLX90640ESFBABSP
TP1: D-; TestPoint_Pad_1.0x1.0mm
TP2: D+; TestPoint_Pad_1.0x1.0mm
TP3: 3V3; TestPoint_Pad_1.0x1.0mm
TP4: GND; TestPoint_Pad_1.0x1.0mm
TP5: EN; TestPoint_Pad_1.0x1.0mm
TP6: IO0; TestPoint_Pad_1.0x1.0mm
TP7: SCL; TestPoint_Pad_1.0x1.0mm
TP8: SDA; TestPoint_Pad_1.0x1.0mm
TP9: VBUS; TestPoint_Pad_1.0x1.0mm
TP10: BATT; TestPoint_Pad_1.0x1.0mm
TP11, TP12, TP13, TP14, TP15: TestPoint; TestPoint_Pad_D1.0mm
TX1: TXD; TestPoint_Pad_1.0x1.0mm
U1: RT9013; SOT-23-5
U2: LIS3MDL; LGA-12_2x2mm_P0.5mm
U3: LSM6DSOWTR; LGA-14_3x2.5mm_P0.5mm_LayoutBorder3x4y; PARTREV 3.0
U4: STC31-C-R3; XDCR_STC31-C-R3; PARTREV 3.2
U5: ESP32-S3-WROOM-1-Espressif; ESP32-S3-WROOM-1
U6: BME680; Bosch_LGA-8_3x3mm_P0.8mm_ClockwisePinNumbering
U7: TQFN-16_L3.0-W3.0-P0.50-BL-EP1.5
U8: SW-SMD_SIQ-02FVS3_1; Manufacturer Part SIQ-02FVS3; LCSC Part Name 拨轮滚轮旋转编码器开关

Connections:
+3V3: C10.2, C11.2, C12.2, C13.2, C14.1, C15.1, C16.1, C19.2, D1.1 (VDD), J2.3, J4.1, JP3.2 (B), R1.1, R2.1, R4.2, R10.1, R11.1, R12.2, R13.1, R17.2, T1.2 (VDD), TP3.1, U2.5 (Vdd), U2.6 (Vdd_IO), U2.10 (~CS), U3.5 (VDDIO), U3.8 (VDD), U3.12 (CS), U4.6 (VDD), U5.2 (3V3), U6.2 (CSB), U6.5 (SDO), U6.6 (VDDIO), U6.8 (VDD), U7.7 (VDD), U7.8 (VDD)
/LASER: Q1.3 (D), TP15.1; also elsewhere on the board
BATT_READ: C8.1, J1.1, TP10.1, U5.6 (GPIO6/TOUCH6/ADC1_CH5)
EN: C1.2, R1.2, RST1.2, TP5.1, U5.3 (EN); also elsewhere on the board
GND: C1.1, C2.1, C3.1, C4.2, C5.2, C6.1, C7.1, C8.2, C9.2, C10.1, C11.1, C12.1, C13.1, C14.2, C15.2, C16.2, C19.1, D1.3 (VSS), J2.2, J3.A1 (GND), J3.A12 (GND), J3.B1 (GND), J3.B12 (GND), J3.S1 (SHIELD), J4.2, JP1.1 (A), JP2.2 (B), Q1.2 (S), R3.2, R5.2, R6.2, R7.1, R16.2, RST1.1, SW1.2, T1.3 (GND), TP4.1, U1.2 (GND), U2.2 (GND), U2.3 (GND), U2.12 (GND), U3.2 (SDX), U3.3 (SCX), U3.6 (GND), U3.7 (GND), U4.1 (VSS), U4.3 (ADDR), U4.5 (VSS), U4.9 (VSS), U4.11 (VSS), U4.13 (EXP), U5.1 (GND), U5.40 (GND), U5.41 (GND), U6.1 (GND), U6.7 (GND), U7.3 (GND), U7.11 (GND), U7.15 (GND), U7.17 (GND), U8.1 (EH), U8.2 (EH), U8.5 (EH), U8.6 (EH), U8.C; also elsewhere on the board
I2C_SCL: J1.6, R11.2, T1.4 (SCL), TP7.1, U2.1 (SCL/SPC), U3.13 (SCL), U4.4 (SCL), U5.12 (GPIO8/TOUCH8/ADC1_CH7/SUBSPICS1), U6.4 (SCK)
I2C_SDA: J1.5, R13.2, T1.1 (SDA), TP8.1, U2.11 (SDA/SDI/SDO), U3.14 (SDA), U4.7 (SDA), U5.10 (GPIO17/U1TXD/ADC2_CH6), U6.3 (SDI)
I2SCLK: J5.2, U5.29 (SPIIO7/GPIO36/FSPICLK/SUBSPICLK), U7.16 (BCLK)
I2SD: R14.1, U5.35 (MTMS/GPIO42)
I2SDIN: J5.3, U5.30 (SPIDQS/GPIO37/FSPIQ/SUBSPIQ), U7.1 (DIN)
I2SLRC: J5.1, U5.28 (SPIIO6/GPIO35/FSPID/SUBSPID), U7.14 (LRCLK)
IO1: J4.3, U5.39 (GPIO1/TOUCH1/ADC1_CH0)
IO2: J4.4, U5.38 (GPIO2/TOUCH2/ADC1_CH1)
LCD_BL: J1.7, U5.24 (GPIO47/SPICLK_P/SUBSPICLK_P_DIFF)
LCD_CS: J1.2, U5.23 (GPIO21)
LCD_DC: J1.4, U5.22 (GPIO14/TOUCH14/ADC2_CH3/FSPIWP/FSPIDQS/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)
LDR: R2.2, R3.1, U5.7 (GPIO7/TOUCH7/ADC1_CH6)
LIS3_INT: U2.7 (INT), U5.11 (GPIO18/U1RXD/ADC2_CH7/CLK_OUT3)
LOAD_SW: R15.2, U5.18 (GPIO10/TOUCH10/ADC1_CH9/FSPICS0/FSPIIO4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)
LSM6_INT1: U3.4 (INT1), U5.5 (GPIO5/TOUCH5/ADC1_CH4)
LSM6_INT2: U3.9 (INT2), U5.4 (GPIO4/TOUCH4/ADC1_CH3)
MISO: J2.5, U5.21 (GPIO13/TOUCH13/ADC2_CH2/FSPIQ/FSPIIO7/S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)
MOSI: J2.4, U5.19 (GPIO11/TOUCH11/ADC2_CH0/FSPICS0/FSPIIO4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)
unnamed: C4.1, J3.A6 (D+), J3.B6 (D+), R9.2
unnamed: C5.1, J3.A7 (D-), J3.B7 (D-), R8.1
unnamed 25: D1.2 (DOUT), LED1.1; also elsewhere on the board
unnamed: J3.A5 (CC1), R6.1
unnamed: J3.B5 (CC2), R5.1
unnamed: JP1.2 (B), R4.1, U2.9 (SDO/SA1)
unnamed: JP2.1 (A), R12.1, U3.1 (SDO/SA0)
unnamed: C3.2, JP3.1 (A), U1.5 (VOUT)
unnamed: Q1.1 (G), R15.1, R16.1
unnamed: C9.1, U2.4 (C1)
unnamed: R10.2, SW1.1, TP6.1, U5.27 (GPIO0/BOOT)
unnamed: TP11.1, U5.32 (MTCK/GPIO39/CLK_OUT3/SUBSPICS1)
unnamed: TP12.1, U5.33 (MTDO/GPIO40/CLK_OUT2)
unnamed 36: RX1.1, U5.36 (U0RXD/GPIO44/CLK_OUT2); also elsewhere on the board
unnamed 37: TX1.1, U5.37 (U0TXD/GPIO43/CLK_OUT1); also elsewhere on the board
unnamed: R7.2, U7.2 (GAIN)
unnamed: TP13.1, U7.10 (OUTN)
unnamed: TP14.1, U7.9 (OUTP)
unnamed: R14.2, R17.1, U7.4 (SD)
ROT_A: U5.34 (MTDI/GPIO41/CLK_OUT1), U8.A
ROT_B: U5.8 (GPIO15/U0RTS/ADC2_CH4/XTAL_32K_P), U8.B
ROT_S: J5.4, U5.31 (GPIO38/FSPIWP/SUBSPIWP), U8.S
SCK: J2.6, U5.20 (GPIO12/TOUCH11/ADC2_CH0/FSPICS0/FSPIIO4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)
SD_CS: J1.3, U5.25 (GPIO48/SPICLK_N/SUBSPICLK_N_DIFF)
TP_INT: J2.7, U5.17 (GPIO9/TOUCH9/ADC1_CH8/FSPIHD/SUBSPIHD)
USB_D+: R9.1, TP2.1, U5.13 (GPIO19/U1RTS/ADC2_CH8/CLK_OUT2/USB_D-)
USB_D-: R8.2, TP1.1, U5.14 (GPIO20/U1CTS/ADC2_CH9/CLK_OUT1/USB_D+)
VBUS: C2.2, C6.2, C7.2, J2.1, J3.A4 (VBUS), J3.A9 (VBUS), J3.B4 (VBUS), J3.B9 (VBUS), TP9.1, U1.1 (VIN), U1.3 (EN)
WS2812: D1.4 (DIN), U5.9 (GPIO16/U0CTS/ADC2_CH5/XTAL_32K_NH5)

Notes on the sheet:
USB-C connector
BUGS: MAX98357 SD Pin Pullup 1M auf 3.3V fehlt C15, C16 auf 10nF hoch
LIS3M muss auf 90° positioniert werden!!!!
SeeedStudio Round Display
SCL 8 SDA 17 LS6I1 5 LS6I2 4 LS3I 18 BATLV 6 MOSI 11 SCK 12 MISO 13 LCD DC 14 LCD CS 21 LCD BL 47
I2C: 0x1C (alt. 0x1E)
RTC I2C: 0x51
Dual Use: LDR or Switch
I2C: 0x6A (alt. 0x6B)
BUGS!!!! USB+ und USB- and ESP32 vertauscht!!!!
LIS3MDL - 3-axis magnetometer
STC31-C - CO2 Sensor
GND
LSM6DSOX - 3-axis accelerometer & 3-axis gyroscope
ROTA 41 ROTB 15 ROTS 38
3V3
I2C: 0x29 (change with R on ADDR)
MAX98357 Audio AMP
HINT: AUDIO NOT with OSPI RAM R8/R16MB ONLY QSPI RAM

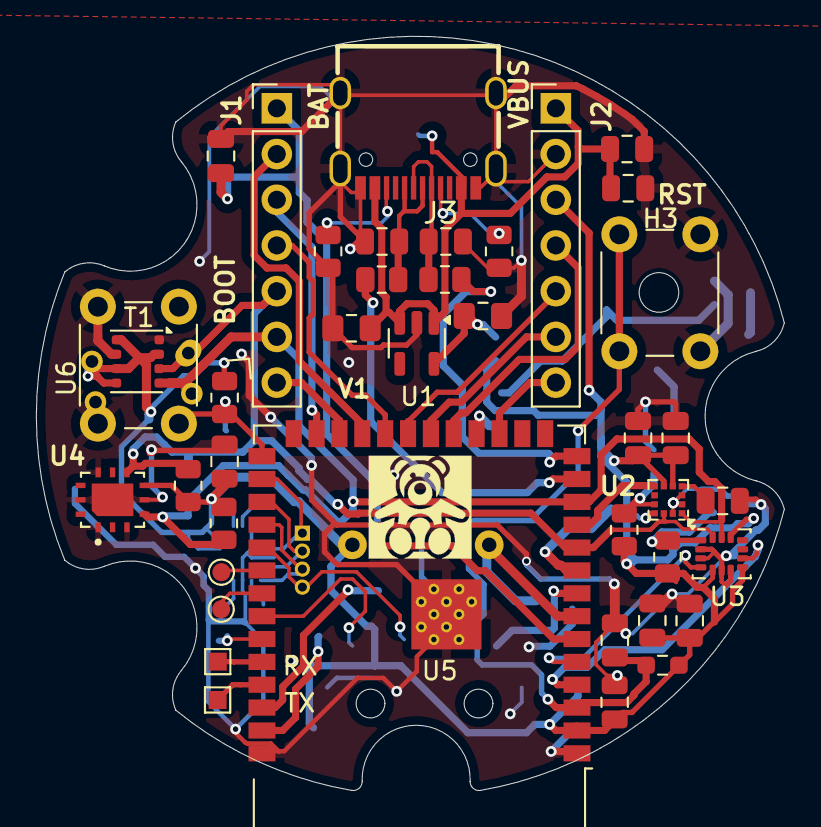
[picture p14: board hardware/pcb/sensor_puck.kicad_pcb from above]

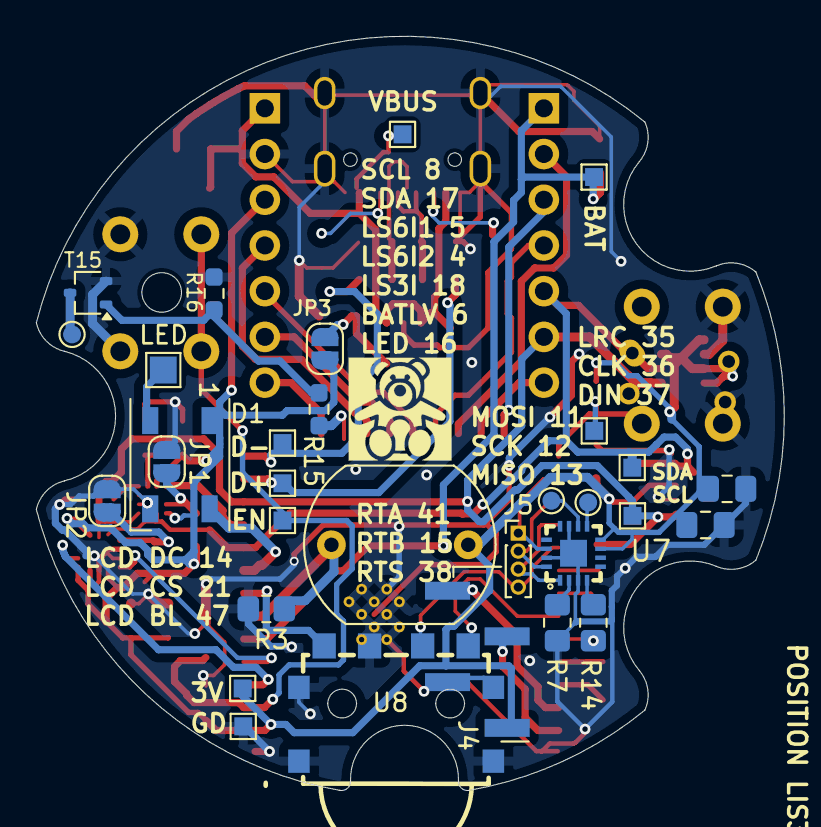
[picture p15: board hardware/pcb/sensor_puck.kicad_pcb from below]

Board: 2 copper layers, 41.6 x 41.9 mm, 75 parts (32 on the bottom side), 52 nets.

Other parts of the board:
LED: LED; TestPoint_Pad_1.5x1.5mm
RST: RST; SW_PUSH_6mm
RX: RXD; TestPoint_Pad_1.0x1.0mm
T15: TestPoint; TestPoint_Pad_D1.0mm
TX: TXD; TestPoint_Pad_1.0x1.0mm

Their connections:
/LASER: T15.1; also elsewhere on the board
EN: RST.2; also elsewhere on the board
GND: RST.1; also elsewhere on the board
unnamed 25: LED.1; also elsewhere on the board
unnamed 36: RX.1; also elsewhere on the board
unnamed 37: TX.1; also elsewhere on the board

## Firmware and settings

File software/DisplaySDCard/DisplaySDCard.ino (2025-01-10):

//Initalisiert Display & SD Card

//Trick: SD Karte ist auf anderem SPI Port als das Display
//declared above void setup()
/*SPIClass * hspi = NULL;
void setup()
hspi = new SPIClass(HSPI);
hspi->begin(14, 2, 15, 13);
if (!SD.begin(SD_CS, *hspi)) {
Serial.println(“Card Mount Failed”);
return;
}*/


#include "SPI.h"
#include "FS.h"
#include "SD.h"
#include "Adafruit_GFX.h"
#include "Adafruit_GC9A01A.h"

#include "USB.h"



#define TFT_RST 42
#define TFT_DC  14
#define TFT_CS  21
#define TFT_SCK  12
#define TFT_MISO  13
#define TFT_MOSI  11
#define TFT_BL 47

#define SD_SS         48 //DAT3
#define SD_MOSI      11 //CMD
#define SD_MISO      13 //DAT0
#define SD_SCK       12 //SCK


USBCDC USBSerial;
//Display
Adafruit_GC9A01A tft(TFT_CS, TFT_DC, TFT_MOSI, TFT_SCK, TFT_RST, TFT_MISO);

//SD Card
SPIClass * hspi = NULL;

void setup() {
  USBSerial.begin();USB.begin();
  USBSerial.println("GC9A01A Test!");
  delay(2000);
  tft.begin();

  //SD_Card_setup();
  //sd_card_checker();
 

  pinMode(TFT_BL, OUTPUT);
  digitalWrite(TFT_BL, HIGH); // Backlight on


  USBSerial.println(F("Benchmark                Time (microseconds)"));
  delay(10);
  USBSerial.print(F("Screen fill              "));
  USBSerial.println(testFillScreen());
  delay(500);

  USBSerial.print(F("Text                     "));
  USBSerial.println(testText());
  delay(3000);

  USBSerial.print(F("Lines                    "));
  USBSerial.println(testLines(GC9A01A_CYAN));
  delay(500);

  USBSerial.print(F("Horiz/Vert Lines         "));
  USBSerial.println(testFastLines(GC9A01A_RED, GC9A01A_BLUE));
  delay(500);

      //declared above void setup()
    
  

  USBSerial.println(F("Done!"));
}

void loop(void) {
  for(uint8_t rotation=0; rotation<4; rotation++) {
    tft.setRotation(rotation);
    testText();
    delay(1000);
  }
}

unsigned long testFillScreen() {
  unsigned long start = micros();
  tft.fillScreen(GC9A01A_BLACK);
  yield();
  tft.fillScreen(GC9A01A_RED);
  yield();
  tft.fillScreen(GC9A01A_GREEN);
  yield();
  tft.fillScreen(GC9A01A_BLUE);
  yield();
  tft.fillScreen(GC9A01A_BLACK);
  yield();
  return micros() - start;
}

unsigned long testText() {
  tft.fillScreen(GC9A01A_BLACK);
  unsigned long start = micros();
  tft.setCursor(0, 0);
  tft.setTextColor(GC9A01A_WHITE);  tft.setTextSize(1);
  tft.println("Hello World!");
  tft.setTextColor(GC9A01A_YELLOW); tft.setTextSize(2);
  tft.println(1234.56);
  tft.setTextColor(GC9A01A_RED);    tft.setTextSize(3);
  tft.println(0xDEADBEEF, HEX);
  tft.println();
  tft.setTextColor(GC9A01A_GREEN);
  tft.setTextSize(5);
  tft.println("Groop");
  tft.setTextSize(2);
  tft.println("I implore thee,");
  tft.setTextSize(1);
  tft.println("my foonting turlingdromes.");
  tft.println("And hooptiously drangle me");
  tft.println("with crinkly bindlewurdles,");
  tft.println("Or I will rend thee");
  tft.println("in the gobberwarts");
  tft.println("with my blurglecruncheon,");
  tft.println("see if I don't!");
  return micros() - start;
}

unsigned long testLines(uint16_t color) {
  unsigned long start, t;
  int           x1, y1, x2, y2,
                w = tft.width(),
                h = tft.height();

  tft.fillScreen(GC9A01A_BLACK);
  yield();

  x1 = y1 = 0;
  y2    = h - 1;
  start = micros();
  for(x2=0; x2<w; x2+=6) tft.drawLine(x1, y1, x2, y2, color);
  x2    = w - 1;
  for(y2=0; y2<h; y2+=6) tft.drawLine(x1, y1, x2, y2, color);
  t     = micros() - start; // fillScreen doesn't count against timing

  yield();
  tft.fillScreen(GC9A01A_BLACK);
  yield();

  x1    = w - 1;
  y1    = 0;
  y2    = h - 1;
  start = micros();
  for(x2=0; x2<w; x2+=6) tft.drawLine(x1, y1, x2, y2, color);
  x2    = 0;
  for(y2=0; y2<h; y2+=6) tft.drawLine(x1, y1, x2, y2, color);
  t    += micros() - start;

  yield();
  tft.fillScreen(GC9A01A_BLACK);
  yield();

  x1    = 0;
  y1    = h - 1;
  y2    = 0;
  start = micros();
  for(x2=0; x2<w; x2+=6) tft.drawLine(x1, y1, x2, y2, color);
  x2    = w - 1;
  for(y2=0; y2<h; y2+=6) tft.drawLine(x1, y1, x2, y2, color);
  t    += micros() - start;

  yield();
  tft.fillScreen(GC9A01A_BLACK);
  yield();

  x1    = w - 1;
  y1    = h - 1;
  y2    = 0;
  start = micros();
  for(x2=0; x2<w; x2+=6) tft.drawLine(x1, y1, x2, y2, color);
  x2    = 0;
  for(y2=0; y2<h; y2+=6) tft.drawLine(x1, y1, x2, y2, color);

  yield();
  return micros() - start;
}

unsigned long testFastLines(uint16_t color1, uint16_t color2) {
  unsigned long start;
  int           x, y, w = tft.width(), h = tft.height();

  tft.fillScreen(GC9A01A_BLACK);
  start = micros();
  for(y=0; y<h; y+=5) tft.drawFastHLine(0, y, w, color1);
  for(x=0; x<w; x+=5) tft.drawFastVLine(x, 0, h, color2);

  return micros() - start;
}

unsigned long testRects(uint16_t color) {
  unsigned long start;
  int           n, i, i2,
                cx = tft.width()  / 2,
                cy = tft.height() / 2;

  tft.fillScreen(GC9A01A_BLACK);
  n     = min(tft.width(), tft.height());
  start = micros();
  for(i=2; i<n; i+=6) {
    i2 = i / 2;
    tft.drawRect(cx-i2, cy-i2, i, i, color);
  }

  return micros() - start;
}

unsigned long testFilledRects(uint16_t color1, uint16_t color2) {
  unsigned long start, t = 0;
  int           n, i, i2,
                cx = tft.width()  / 2 - 1,
                cy = tft.height() / 2 - 1;

  tft.fillScreen(GC9A01A_BLACK);
  n = min(tft.width(), tft.height());
  for(i=n; i>0; i-=6) {
    i2    = i / 2;
    start = micros();
    tft.fillRect(cx-i2, cy-i2, i, i, color1);
    t    += micros() - start;
    // Outlines are not included in timing results
    tft.drawRect(cx-i2, cy-i2, i, i, color2);
    yield();
  }

  return t;
}

unsigned long testFilledCircles(uint8_t radius, uint16_t color) {
  unsigned long start;
  int x, y, w = tft.width(), h = tft.height(), r2 = radius * 2;

  tft.fillScreen(GC9A01A_BLACK);
  start = micros();
  for(x=radius; x<w; x+=r2) {
    for(y=radius; y<h; y+=r2) {
      tft.fillCircle(x, y, radius, color);
    }
  }

  return micros() - start;
}

unsigned long testCircles(uint8_t radius, uint16_t color) {
  unsigned long start;
  int           x, y, r2 = radius * 2,
                w = tft.width()  + radius,
                h = tft.height() + radius;

  // Screen is not cleared for this one -- this is
  // intentional and does not affect the reported time.
  start = micros();
  for(x=0; x<w; x+=r2) {
    for(y=0; y<h; y+=r2) {
      tft.drawCircle(x, y, radius, color);
    }
  }

  return micros() - start;
}

unsigned long testTriangles() {
  unsigned long start;
  int           n, i, cx = tft.width()  / 2 - 1,
                      cy = tft.height() / 2 - 1;

  tft.fillScreen(GC9A01A_BLACK);
  n     = min(cx, cy);
  start = micros();
  for(i=0; i<n; i+=5) {
    tft.drawTriangle(
      cx    , cy - i, // peak
      cx - i, cy + i, // bottom left
      cx + i, cy + i, // bottom right
      tft.color565(i, i, i));
  }

  return micros() - start;
}

unsigned long testFilledTriangles() {
  unsigned long start, t = 0;
  int           i, cx = tft.width()  / 2 - 1,
                   cy = tft.height() / 2 - 1;

  tft.fillScreen(GC9A01A_BLACK);
  start = micros();
  for(i=min(cx,cy); i>10; i-=5) {
    start = micros();
    tft.fillTriangle(cx, cy - i, cx - i, cy + i, cx + i, cy + i,
      tft.color565(0, i*10, i*10));
    t += micros() - start;
    tft.drawTriangle(cx, cy - i, cx - i, cy + i, cx + i, cy + i,
      tft.color565(i*10, i*10, 0));
    yield();
  }

  return t;
}

unsigned long testRoundRects() {
  unsigned long start;
  int           w, i, i2,
                cx = tft.width()  / 2 - 1,
                cy = tft.height() / 2 - 1;

  tft.fillScreen(GC9A01A_BLACK);
  w     = min(tft.width(), tft.height());
  start = micros();
  for(i=0; i<w; i+=6) {
    i2 = i / 2;
    tft.drawRoundRect(cx-i2, cy-i2, i, i, i/8, tft.color565(i, 0, 0));
  }

  return micros() - start;
}

unsigned long testFilledRoundRects() {
  unsigned long start;
  int           i, i2,
                cx = tft.width()  / 2 - 1,
                cy = tft.height() / 2 - 1;

  tft.fillScreen(GC9A01A_BLACK);
  start = micros();
  for(i=min(tft.width(), tft.height()); i>20; i-=6) {
    i2 = i / 2;
    tft.fillRoundRect(cx-i2, cy-i2, i, i, i/8, tft.color565(0, i, 0));
    yield();
  }

  return micros() - start;
}




void SD_Card_setup(void){

   hspi = new SPIClass(HSPI);
  hspi->begin(SD_SCK, SD_MISO, SD_MOSI, SD_SS);
   if (!SD.begin(SD_SS, *hspi)) {
     USBSerial.println("Card Mount Failed");
     return;
   }
  uint8_t cardType = SD.cardType();

  if(cardType == CARD_NONE){
    USBSerial.println("No SD card attached");
    return;
  }

  Serial.print("SD Card Type: ");
  if(cardType == CARD_MMC){
    USBSerial.println("MMC");
  } else if(cardType == CARD_SD){
    USBSerial.println("SDSC");
  } else if(cardType == CARD_SDHC){
    USBSerial.println("SDHC");
  } else {
    USBSerial.println("UNKNOWN");
  }

  uint64_t cardSize = SD.cardSize() / (1024 * 1024);
  USBSerial.printf("SD Card Size: %lluMB\n", cardSize);
}

void sd_card_checker(void){

  listDir(SD, "/", 0);
  createDir(SD, "/mydir");
  listDir(SD, "/", 0);
  removeDir(SD, "/mydir");
  listDir(SD, "/", 2);
  writeFile(SD, "/hello.txt", "Hello ");
  appendFile(SD, "/hello.txt", "World!\n");
  readFile(SD, "/hello.txt");
  deleteFile(SD, "/foo.txt");
  renameFile(SD, "/hello.txt", "/foo.txt");
  readFile(SD, "/foo.txt");
  testFileIO(SD, "/test.txt");
  Serial.printf("Total space: %lluMB\n", SD.totalBytes() / (1024 * 1024));
  Serial.printf("Used space: %lluMB\n", SD.usedBytes() / (1024 * 1024));


}


void listDir(fs::FS &fs, const char * dirname, uint8_t levels){
  USBSerial.printf("Listing directory: %s\n", dirname);

  File root = fs.open(dirname);
  if(!root){
    USBSerial.println("Failed to open directory");
    return;
  }
  if(!root.isDirectory()){
    USBSerial.println("Not a directory");
    return;
  }

  File file = root.openNextFile();
  while(file){
    if(file.isDirectory()){
      USBSerial.print("  DIR : ");
      USBSerial.println(file.name());
      if(levels){
        listDir(fs, file.name(), levels -1);
      }
    } else {
      USBSerial.print("  FILE: ");
      USBSerial.print(file.name());
      USBSerial.print("  SIZE: ");
      USBSerial.println(file.size());
    }
    file = root.openNextFile();
  }
}

void createDir(fs::FS &fs, const char * path){
  USBSerial.printf("Creating Dir: %s\n", path);
  if(fs.mkdir(path)){
    USBSerial.println("Dir created");
  } else {
    USBSerial.println("mkdir failed");
  }
}

void removeDir(fs::FS &fs, const char * path){
  USBSerial.printf("Removing Dir: %s\n", path);
  if(fs.rmdir(path)){
    USBSerial.println("Dir removed");
  } else {
    USBSerial.println("rmdir failed");
  }
}

void readFile(fs::FS &fs, const char * path){
  USBSerial.printf("Reading file: %s\n", path);

  File file = fs.open(path);
  if(!file){
   USBSerial.println("Failed to open file for reading");
    return;
  }

  USBSerial.print("Read from file: ");
  while(file.available()){
    USBSerial.write(file.read());
  }
  file.close();
}

void writeFile(fs::FS &fs, const char * path, const char * message){
  USBSerial.printf("Writing file: %s\n", path);

  File file = fs.open(path, FILE_WRITE);
  if(!file){
    USBSerial.println("Failed to open file for writing");
    return;
  }
  if(file.print(message)){
    USBSerial.println("File written");
  } else {
    USBSerial.println("Write failed");
  }
  file.close();
}

void appendFile(fs::FS &fs, const char * path, const char * message){
  USBSerial.printf("Appending to file: %s\n", path);

  File file = fs.open(path, FILE_APPEND);
  if(!file){
    USBSerial.println("Failed to open file for appending");
    return;
  }
  if(file.print(message)){
      USBSerial.println("Message appended");
  } else {
    USBSerial.println("Append failed");
  }
  file.close();
}

void renameFile(fs::FS &fs, const char * path1, const char * path2){
  USBSerial.printf("Renaming file %s to %s\n", path1, path2);
  if (fs.rename(path1, path2)) {
    USBSerial.println("File renamed");
  } else {
    USBSerial.println("Rename failed");
  }
}

void deleteFile(fs::FS &fs, const char * path){
  USBSerial.printf("Deleting file: %s\n", path);
  if(fs.remove(path)){
    USBSerial.println("File deleted");
  } else {
    USBSerial.println("Delete failed");
  }
}

void testFileIO(fs::FS &fs, const char * path){
  File file = fs.open(path);
  static uint8_t buf[512];
  size_t len = 0;
  uint32_t start = millis();
  uint32_t end = start;
  if(file){
    len = file.size();
    size_t flen = len;
    start = millis();
    while(len){
      size_t toRead = len;
      if(toRead > 512){
        toRead = 512;
      }
      file.read(buf, toRead);
      len -= toRead;
    }
    end = millis() - start;
    USBSerial.printf("%u bytes read for %u ms\n", flen, end);
    file.close();
  } else {
    USBSerial.println("Failed to open file for reading");
  }


  file = fs.open(path, FILE_WRITE);
  if(!file){
    USBSerial.println("Failed to open file for writing");
    return;
  }

  size_t i;
  start = millis();
  for(i=0; i<2048; i++){
    file.write(buf, 512);
  }
  end = millis() - start;
  USBSerial.printf("%u bytes written for %u ms\n", 2048 * 512, end);
  file.close();
}

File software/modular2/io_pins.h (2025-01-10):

#pragma once
#ifndef _IO_PINS_H
#define _IO_PINS_H

#define ROTARY_ENCODER_A_PIN 41
#define ROTARY_ENCODER_B_PIN 15
#define ROTARY_ENCODER_BUTTON_PIN 38
#define MAX_ROTARY_VALUE 150

#define SCREEN_WIDTH 240
#define SCREEN_HEIGHT 240
#define screen_rotation 1
#define SDA2 17
#define SCL2 8

#define SD_SS         48

#define SPI_MOSI      11
#define SPI_MISO      13
#define SPI_SCK       12

#define I2S_DOUT      37
#define I2S_BCLK      36
#define I2S_LRC       35
#define I2S_SD        42

#define DISP_CS       21
#define DISP_DC       14
#define DISP_RST      0
#define DISP_BLK      47

#define DISP_TP       9

#define LSM6_INT1       5
#define LSM6_INT2       4
#define LIS3M_INT1      18

#define NUMPIXELS     1
#define  LEDPIN     16

#endif

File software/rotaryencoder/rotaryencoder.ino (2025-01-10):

#include "credentials.h"
#include "USB.h"

#include <Adafruit_NeoPixel.h>
USBCDC USBSerial;

int vorher_message =0;
int counter = 0;
int lastcounter=0;
int counter_last=0;
int drehregler=0;
long lastTrigger = 0;
long lastTrigger_LEDS=0;
boolean ROTARY_A_NOW = 0;
boolean ROTARY_B_NOW = 0;
boolean ROTARY_A_LAST = 0;
boolean BUTTON_CLICK = 0;





// When setting up the NeoPixel library, we tell it how many pixels,
// and which pin to use to send signals. Note that for older NeoPixel
// strips you might need to change the third parameter -- see the
// strandtest example for more information on possible values.
Adafruit_NeoPixel pixels(ANZAHL_LEDS, RGB_LED_DATA_PIN, NEO_GRB + NEO_KHZ800);
#define DELAYVAL 500 // Time (in milliseconds) to pause between pixels
/* nur prüfen welcher Pin zuerst veränert wurde A oder B
 *  Wenn A zuerst dann Clockwise
 *  Bei B zuerst dann Counter Clockwise
*/
/*ISR ROUTINEN */
void IRAM_ATTR rotary_movement() {
  ROTARY_A_NOW = digitalRead(ROTARY_ENCODER_A_PIN);
  ROTARY_B_NOW = digitalRead(ROTARY_ENCODER_B_PIN);
  if (ROTARY_A_NOW != ROTARY_B_NOW){// nur beim ersten voreilenden Wechsel erfassen... den zweiten Wechsel ignorieren
    if (ROTARY_A_NOW != ROTARY_A_LAST){
      //A hat sich verändert Im Uhrzeigersinn
      if (counter < max_counter)counter++;
    }
    else{
      //B hat sich zuerst verändert Gegnuhrzeigersinn
      if (counter > min_counter)counter--;
    }
  }
    
}

void IRAM_ATTR rotary_button() {
  BUTTON_CLICK = 1;  
}

/*ISR ROUTINEN ENDE */
void rotary_onButtonClick() {
    if (BUTTON_CLICK != 0){ 
      //blinky(2, 50);
      counter = 0;
      lastcounter=0;
      USBSerial.println("Button"); 
      Serial.println("Button"); 
      //LEDS_weiss();
      BUTTON_CLICK = 0; 
    }
}

void rotary_loop() {
  if (lastcounter!=counter){
    if (counter > lastcounter){
      USBSerial.print("Clockwise:"); 
      Serial.print("Clockwise:"); 
      //blinky(2, 100);
    }
    if (counter < lastcounter){
      USBSerial.print("andersRum:"); 
      Serial.print("andersRum:"); 
      //blinky(2, 100);
    }
    lastcounter = counter;
    USBSerial.println(counter);
    Serial.println(counter);
  }
}

void rotary_encoder_setup(){
  
  pinMode(ROTARY_ENCODER_A_PIN, INPUT_PULLUP);
  pinMode(ROTARY_ENCODER_B_PIN, INPUT_PULLUP);
  pinMode(ROTARY_ENCODER_BUTTON_PIN, INPUT_PULLUP);
  

  attachInterrupt(digitalPinToInterrupt(ROTARY_ENCODER_A_PIN), rotary_movement, FALLING);
  attachInterrupt(digitalPinToInterrupt(ROTARY_ENCODER_B_PIN), rotary_movement, FALLING);
  attachInterrupt(digitalPinToInterrupt(ROTARY_ENCODER_BUTTON_PIN), rotary_button, CHANGE);
}

void setup() {
  // put your setup code here, to run once:
  delay(2000);
  USBSerial.begin(115200);USB.begin();
  delay(2000);
  Serial.begin(115200);
  delay(1000);
  USBSerial.print("start up ..");
  Serial.print("start up ..");
  pixels.begin(); // INITIALIZE NeoPixel strip object (REQUIRED)
  pixels.clear(); // Set all pixel colors to 'off'
  rotary_encoder_setup();
  lastTrigger = millis();
  for(int i=0; i<ANZAHL_LEDS; i++) { // For each pixel...

    // pixels.Color() takes RGB values, from 0,0,0 up to 255,255,255
    // Here we're using a moderately bright green color:
    pixels.setPixelColor(i, pixels.Color(0, 50, 0));

    pixels.show();   // Send the updated pixel colors to the hardware.

    delay(DELAYVAL); // Pause before next pass through loop
  }
}

void loop() {
  // put your main code here, to run repeatedly:
  long now = millis();
  if(now - lastTrigger > (timeSeconds)){
    rotary_loop();
    rotary_onButtonClick();
    lastTrigger = millis();                              
  }
}
